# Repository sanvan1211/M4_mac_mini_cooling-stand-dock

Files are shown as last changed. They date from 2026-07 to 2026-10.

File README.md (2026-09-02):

# M4 Mac Mini Cooling Stand / Dock
 
An elevated cooling stand for the Apple M4 Mac mini, designed from scratch in Onshape. It lifts the mini off the desk, mounts a 120mm fan underneath that blows cool air up into the mini's bottom intake, and adds RGB underglow, powered over USB with a single on/off switch.
 
My first CAD project, built through [Hack Club Stardance](https://stardance.hackclub.com/home) to learn CAD. There is a very simply electronics component to this project (wiring the fan + switch) 

Link to design on Onshape: [Mac Mini Cooling Dock]((https://cad.onshape.com/documents/3fbcf659d7555b2671177b8a/w/d5bac3fdae6cccac52d5566e/e/496516c27ea7f88feafa57b4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))
 
> **Status:** parts arrived 
- Amazon: razer kunai fan (arrived)
- Aliexpress: wires and additional electronics + heat inserts
- HACKCLUB Printing Legion

> 
 
## How it works
 
The enclosure sits under the mini. A 120mm aRGB fan mounts to the underside of the top plate and blows **up** through a central airflow cutout into the mini's intake. Intake air reaches the fan through vent slots on all four walls. Fan + LEDs run over USB (dock or wall adapter), with one rocker switch cutting power to both.
 
```
USB-A power -> trunk cable (switch inline) -> Y-splitter
   -> boost cable (5V->12V) -> fan motor (4-pin PWM)
   -> aRGB controller       -> fan LEDs (3-pin aRGB)
```
 
## Specs
 
| Feature | Spec |
|---|---|
| Footprint | 130 × 130 mm |
| Plate thickness | 6 mm |
| Wall height | 32 mm (fits the 25 mm fan with clearance) |
| Airflow cutout | ~108 mm, radiused inlet to reduce flow separation |
| Fan mounting | 4 bosses + M4 heat-set inserts, 105 mm pattern |
| Reinforcement | Corner gussets bracing bosses to walls |
| Venting | Vertical slots on all four walls |
| Rear | Switch cutout (19.2 × 12.7 mm) + cable hole (~10 mm) |
 
## Files
 
- **[BOM.md](BOM.md)** — full parts list, links, cost (~$70 core build)
- **[reflections.md](reflections.md)** — what I learned building it
- `cad/` — STEP (source) + STL (for printing)
## Assembly notes
 
- Melt M4 heat-set inserts into the four bosses.
- Bolt the fan to the underside, airflow arrow pointing **up**.
- Splice the switch inline on the USB 5V wire, then split to the boost cable (motor) and aRGB controller (LEDs).
- Walls are 8 mm — thicker than the switch's snap clips, so it's friction-fit for v1 (thinned pocket planned for v2).
- Add silicone feet for grip and a small air gap.

## Roadmap
 
- [ ] Print v1 and test-fit
- [ ] Assemble and verify wiring
- [ ] Thermal test: temps with stand off vs. on
- [ ] v2 tweaks from the print
- [ ] Future: CFD airflow sim

## Schematics: 


## Screenshots in onshape 



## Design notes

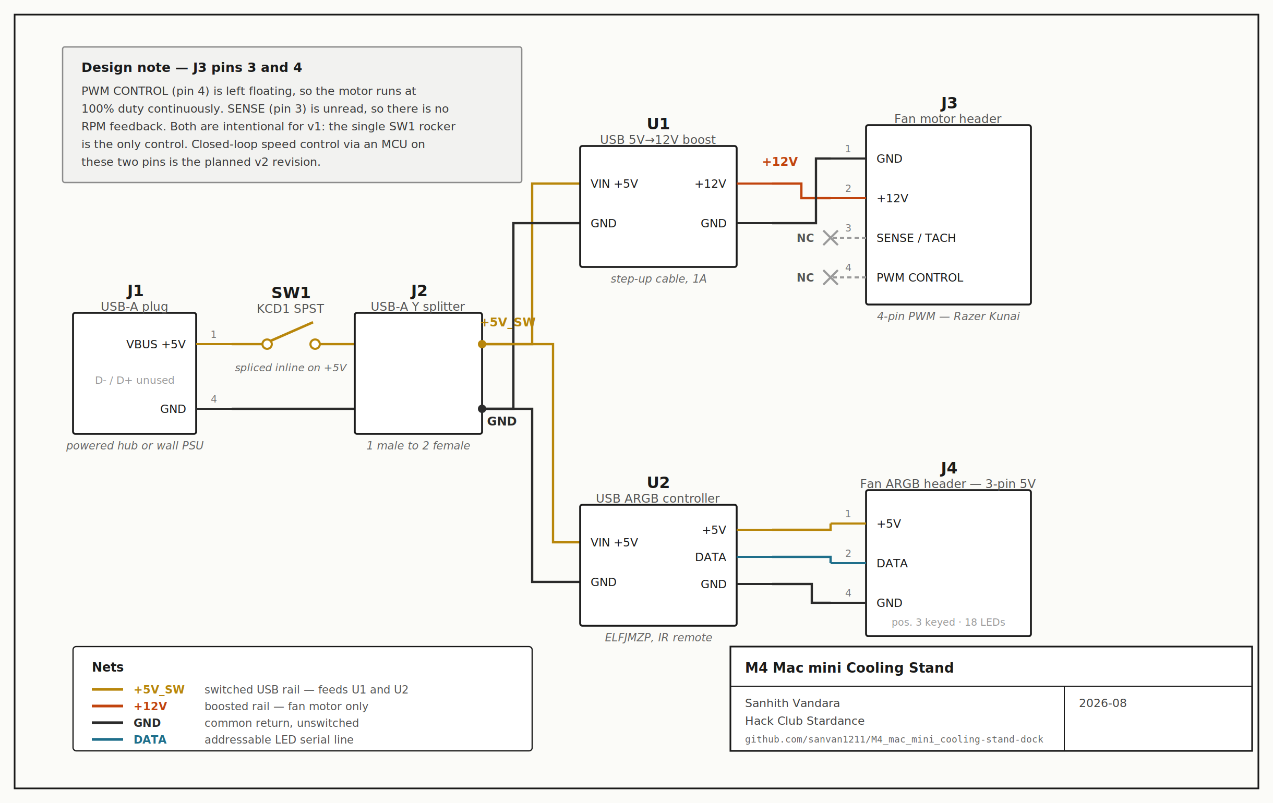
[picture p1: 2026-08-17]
SCHEMATICS/schematic.png

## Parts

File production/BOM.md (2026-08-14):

# Bill of Materials — M4 Mac Mini Cooling Stand / Dock

**Project:**  cooling stand for the M4 Mac mini
**Author:** Sanhith Vandara
**Version:** v2 (A-tier submission)
**Last updated:** August 2026

**Requested funding: $64.50 against the $120 A-tier budget.**

Commodity parts are sourced from AliExpress. Two parts stay on Amazon for spec reasons
documented below. Prices are pre-order estimates — confirm against the live listing before
ordering, since AliExpress pricing moves and listings are frequently relisted.

---

## Parts

| # | Part | Purpose | Source | Est. price |
|---|---|---|---|---|
| 1 | Razer Kunai Hydraulic 120mm aRGB Fan | Main cooling fan + underglow | Amazon | $35.00 |
| 2 | USB 5V→12V step-up cable (3/4-pin fan end) | Boosts USB 5V to 12V for the fan motor | AliExpress | $2.00 |
| 3 | ELFJMZP USB 5V 3-pin ARGB controller | Drives the fan LEDs from USB | Amazon | $10.00 |
| 4 | USB-A 1→2 Y splitter cable | Splits switched power to fan + LED branches | AliExpress | $1.50 |
| 5 | USB 2.0 A-male to A-female extension (1m) | Trunk cable — switch splices inline here | AliExpress | $1.50 |
| 6 | KCD1 mini rocker switch (5-pack) | Master on/off | AliExpress | $1.80 |
| 7 | M4 brass heat-set inserts (20-pack) | Threads in the printed bosses | AliExpress | $2.20 |
| 8 | M4 × 20mm machine screws (20-pack) | Mount the fan into the inserts | AliExpress | $1.80 |
| 9 | Heat-set insert soldering tips | Seats the brass inserts squarely | AliExpress | $3.00 |
| 10 | Heat shrink tubing assortment | Insulate the switch splice | AliExpress | $1.50 |
| 11 | Silicone adhesive feet (20-pack) | Grip + small bottom air gap | AliExpress | $1.20 |
| 12 | PETG filament — 150 g consumed | Prints the enclosure | Amazon | $3.00 |
| | **Total** | | | **$64.50** |

Amazon: $48.00 · AliExpress: $16.50 · **A-tier headroom remaining: $55.50**

**Filament is costed at material consumed, not spool price.** The enclosure uses ~150 g of
a 1 kg PETG spool at ~$20/kg, so the material cost of one unit is $3.00. Note that filament
is not sold in 150 g units — the smallest practical purchase is either a 1 kg spool (~$20)
or a 250 g sample spool (~$8–10). See the pro-rating note below.

Full links are in `BOM.csv`. Spec-critical parts carry direct item links; interchangeable
commodity parts carry AliExpress category search URLs, which stay valid when individual
listings are relisted.

## Covered elsewhere — not funded by this BOM

| Item | Covered by |
|---|---|
| Soldering iron | Hackpad Soldering Iron Grant — $18, one-time |
| Enclosure print service | Printing Legion Grant — $5 shipping credit, under 300 g (optional alternative) |
| Digital calipers | Already owned |
| Hot glue gun | Already owned — seats the switch, not the inserts |

---

## Two parts that could not be substituted

**ARGB controller — stays on Amazon.** Nearly every ARGB controller sold on AliExpress
draws power over **SATA**, from a desktop PSU. This build has no PSU; the entire power
topology runs from a single USB-A source. A SATA controller would either not work or
require an additional USB→SATA adapter, adding a part and a failure point to save about
$7 on a budget with $58 of slack. The USB-native ELFJMZP unit is kept.

**Step-up cable — connector type matters.** Most 5V→12V USB boost cables terminate in a
**5.5 × 2.1 mm barrel jack**, which will not mate with a PC fan. The required variant ends
in a 3-pin/4-pin fan connector. Confirm the connector in the listing photos before ordering.

---

## What changed from v1

The v1 BOM totalled ~$134, sourced entirely from Amazon, with a separate tools table.

- **Fan kept as-is.** The Razer Kunai is the one line where the brand buys something real —
  hydraulic bearing, 18 addressable LEDs, a known noise profile. Held at $35.
- **Interchangeable parts moved to AliExpress**, saving ~$55: cables, switch, fasteners,
  heat shrink, feet. Identical specs; the Amazon premium was markup, not quality.
- **Two parts deliberately not moved** — see the section above.
- **Multi-packs downsized.** 50 inserts and a 10-pack of switches exceeded what one build
  needs; 20-packs and 5-packs cost less and waste less.
- **Filament re-added at consumed cost ($3.00), not spool cost ($20).** v1 charged a full
  1 kg spool to a build that uses 150 g.
- **Soldering iron removed ($22).** Covered by the Hackpad grant.
- **Insert-setting tips added ($3).** The iron alone cannot seat inserts squarely.
- **Consolidated to one BOM.** v1 had a `.md` and a `.csv` that disagreed on totals.
  `BOM.csv` is the source of truth; this file mirrors it.

## Sourcing and sequencing notes

- **Claim the Hackpad iron before ordering tips.** Insert tips thread onto the iron and
  thread standards differ between models. Confirm which iron ships, then buy matching tips.
- **AliExpress ships in roughly 2–5 weeks.** The iron gates assembly — both the inserts and
  the switch splice need it. Order early.
- **Buy from as few sellers as possible.** Ten orders means ten shipments and ten chances
  for shipping fees to creep in.
- **Prefer a fluid or hydraulic bearing** if substituting the fan later. This sits on a desk
  at ear level, and sleeve-bearing fans whine.
- **Filament pro-rating.** This BOM lists $3.00 — the value of plastic actually consumed. A
  spool cannot be bought in 150 g units, so the real out-of-pocket purchase is ~$20 for 1 kg
  (leaving 850 g for future prints) or ~$8–10 for a 250 g sample spool. If reimbursement is
  tied to receipts rather than consumption, submit the spool price instead; the budget
  absorbs it either way ($81.50 of $120 at full spool price).
- **Insert-setting temperature:** roughly 20–40 °C above print temperature. PETG prints at
  230–250 °C, so set the iron near 260–270 °C. A hot glue gun tops out around 200 °C and
  cannot do this job.

---

## Key specifications

**Fan — Razer Kunai 120mm**
- Dimensions: 120 × 120 × 25 mm
- Rated voltage / current: 12V DC / 0.28 A
- Connectors: 4-pin PWM (motor) + 3-pin 5V aRGB (lighting)
- Mounting: standard 120mm pattern — 105 × 105 mm hole square, M4 screws
- 18 addressable LEDs

**Enclosure (3D printed)**
- Footprint: 130 × 130 mm
- Plate thickness: 6 mm
- Wall height: 32 mm (houses the 25 mm fan with clearance)
- Central airflow cutout: ~108 mm, radiused inlet to reduce flow separation
- Fan mounting: 4 bosses with M4 heat-set inserts, corner gussets for support
- Venting: vertical intake slots on all four walls
- Rear: switch cutout (19.2 × 12.7 mm) + cable exit hole (~10 mm)
- Print weight: ~150 g (under the Printing Legion 300 g limit)

**Power / wiring topology**
```
USB-A power (dock or wall)
   -> trunk cable (switch spliced inline on the 5V wire)
      -> Y-splitter
         -> boost cable (5V->12V) -> fan motor (4-pin PWM)
         -> aRGB controller       -> fan LEDs (3-pin aRGB)
```
The single switch cuts power to both the fan motor and the LEDs at once.

---

## Notes

- **Power source:** runs off a powered USB-A source (dock or wall), independent of the
  mini's ports — keeps the mini's ports free and avoids drawing the combined fan + LED
  current through one port.
- **Switch fit:** walls are 8 mm thick; the KCD1's snap clips want ~2 mm, so the switch is
  friction-fit and hot-glued for v1. A thinned mounting pocket is a planned v2 improvement.
- **Airflow:** fan blows **up** into the mini's intake. Wall vents are **intake** for the
  fan; the mini exhausts its own hot air out its rear, above the enclosure.
- **Fan speed:** the PWM pin is currently unconnected, so the motor runs at 100% duty.
  Closed-loop speed control is the obvious use of the remaining headroom.

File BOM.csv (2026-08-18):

Item | Category | Purpose | Source | Est. Price (USD) | Link | Link Type
Razer Kunai Hydraulic 120mm aRGB Fan | Fan | Main cooling fan + underglow | Amazon | 28.00 | https://www.amazon.com/Razer-Kunai-Hydraulic-120MM-aRGB/dp/B09JRMGLQF | item
USB 5V to 12V Step-Up Cable (3/4-pin fan end) | Power | Boosts USB 5V to 12V for fan motor | AliExpress | 2.00 | https://www.aliexpress.com/item/1005006048065687.html | item
3-Pin ARGB USB Controller | Lighting | Drives fan LEDs from USB | Amazon | 7.00 | https://www.amazon.com/ELFJMZP-ARGB-LED-Controller-3-Pin/dp/B0FLY3J3YZ | item
KCD1 Mini Rocker Switch | Switch | Master on/off for unit | AliExpress | 1.50 | https://www.aliexpress.com/w/wholesale-kcd1-rocker-switch.html | search
M4 Brass Heat-Set Inserts (20-pack) | Fasteners | Threads in printed bosses | AliExpress | 2.20 | https://www.aliexpress.com/w/wholesale-m4-brass-heat-set-insert.html | search
M4 x 20mm Machine Screws (20-pack) | Fasteners | Mount fan into inserts | AliExpress | 1.80 | https://www.aliexpress.com/w/wholesale-m4-hex-socket-cap-screw.html | search
Heat Shrink Tubing Assortment | Wiring | Insulate switch splice | AliExpress | 1.50 | https://www.aliexpress.com/w/wholesale-heat-shrink-tube-assortment-kit.html | search
PETG Filament - 150g consumed | Materials | Prints the enclosure | AliExpress | 3.00 | https://www.aliexpress.com/w/wholesale-petg-filament-1-75mm.html | search
Hackpad Soldering Grant | Grant | Covers soldering/tooling costs | Hack Club | 18.00 |  | grant
TOTAL |  |  |  | 65.00

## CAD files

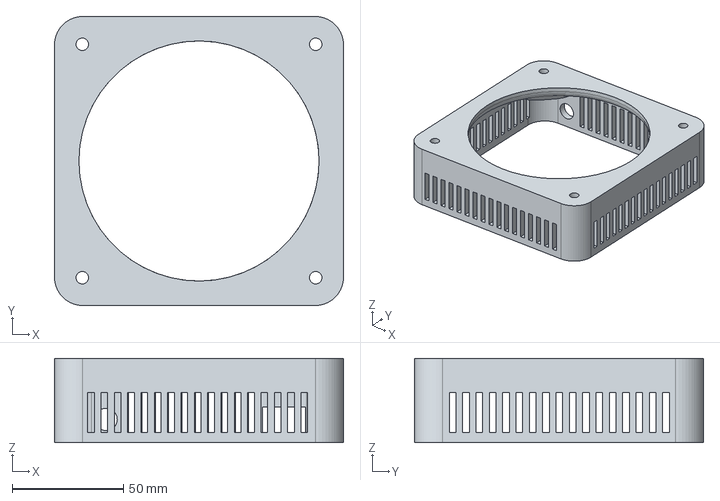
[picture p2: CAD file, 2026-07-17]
CAD/m4_mac_mini_cooling_dock.step
130.0 x 130.0 x 38.0 mm

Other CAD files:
production/m4_mac_mini_cooling_stand.stl

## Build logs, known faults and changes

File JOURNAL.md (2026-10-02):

# M4 Mac mini cooling dock project Journal

## This is my journal for this project

#### I am doing this project for a few different reasons:

1. To improve my CAD skills.
2. To keep my Mac mini cool during heavy workloads.
3. To have fun building small engineering projects.

This project is being completed through Hack Club.

### Tools/Software used: 
Claude - Drafting ideas, searching for similar projects, 
Onshape- CAD Software 

# Entry 1: setting up Onshape and Selecting a fan for project 
#### July 13 2026: 14:30-16:50 hours 

### Fan Comparison

| Fan | Approx. Price | Connector Type | Pros | Cons | Decision |
|---|---:|---|---|---|---|
| **Arctic P12 A-RGB** | ~$16 ($7 on sale (amazon) | Standard 4-pin PWM + 3-pin 5V ARGB | Affordable, quiet, excellent airflow, low power consumption, easy to wire | Simpler appearance than the Razer fan | Excellent value and a strong alternative |
| **Razer Kunai 120mm ARGB** | ~$25–45 | Standard 4-pin PWM + 3-pin 5V ARGB | Premium design, customizable lighting, quality construction, compatible with USB-to-12V conversion | More expensive and slightly louder at higher RPMs | ** Selected for the project** |
| **Corsair iCUE LINK LX120 RGB** | ~$35–45 | Proprietary Corsair iCUE LINK | High-quality fan with premium lighting effects | Requires Corsair's proprietary ecosystem and controller, making integration more difficult | Not selected due to unnecessary complexity |
|**Noctua NF-P12 redux-1700 PWM** | $16 | Standard 4-Pin PWM + 3 pin 5V A-RGB| affordable| Good value and strong alternate | boxy-like shape 

https://m.media-amazon.com/images/I/611T+f1qgRL._SX385_.jpg

When selecting a fan for this project, I considered three main factors: **compatibility**, **ease of integration**, and **overall appearance**.

While the **Arctic P12 A-RGB** offers the best value for the money, I ultimately chose the **Razer Kunai 120mm ARGB** because I wanted the finished build to be both functional and visually appealing. Since this is my first hardware project through **Hack Club Stardance**, I wanted to create something I would be proud to display and document and share with others.

Unlike the **Corsair iCUE LINK LX120**, which relies on a proprietary ecosystem, the Razer Kunai uses standard **4-pin PWM** and **3-pin 5V ARGB** connectors. This makes it much easier to power and integrate into a custom USB-powered cooling stand without requiring additional proprietary hardware.

I also already own several Razer products, including a **Razer Basilisk (V3) mouse **, **Razer x Gillette razor**, and **Razer Kraken X headset**. As a result, I have developed an appreciation for Razer's design language and product aesthetic and choosing the Kunai allows the project to fit naturally alongside the rest of my setup.

The customizable lighting adds a polished, premium appearance to the final build. Although it does not improve cooling performance, it makes the project more engaging to showcase in photos, videos, and GitHub documentation. I also have the Razer Synapse app installed on my Mac mini- so integrated it with the fan and my mouse would be cool as well. 

The Razer Kunai offers the right balance between performance, compatibility, and aesthetics. While it costs more than the Arctic alternative, I believe the improved appearance and straightforward integration make it the best fit for this project and my learning goals.

I stumbled upon some CAD models of a very similar design that I want to implement in my final design:



https://makerworld.bblmw.com/makerworld/model/USf0e74c0e39cc1d/design/2025-01-12_810aa729b34ec.jpg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,w_1000/format,webp 

https://makerworld.bblmw.com/makerworld/model/USf0e74c0e39cc1d/757755172/instance/b3691a0717b74142.png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

https://makerworld.bblmw.com/makerworld/model/USd09a412849dba9/design/2025-08-04_63280fa71a038.jpg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,w_1000/format,webp

After 'Clauding' and searching the internet- ive came up with this brainstorm using canva: 



# Entry 2: Desining the dock in onshape 
#### July 14 2026 

Today was one of those days where I got humbled, I did not know CAD was going to be this tedious. 

I sat down thinking I'd knock out a decent chunk of the stand in a couple of hours. In my head it was basically, "draw a square, cut a few holes, done." Instead, I spent the first hour just learning how Onshape actually wants you to think. It's funny because I'm so used to writing code (or vibecoding) where you can usually figure out what's wrong from an error message. CAD isn't like that at all. If you click the wrong face, forget a constraint, or select one extra sketch region, the entire feature changes and you don't even realize why. Even if its off by a few degrees or millimeters, the entire design can be the opposite of what you intended for. 

I started by creating the base plate for the stand. I sketched out a **150 mm × 150 mm** square, learned how to fully define a sketch with dimensions, and extruded it into a **4 mm thick** plate. That alone taught me more than I expected. I finally understood why people stress making sketches "fully constrained" instead of just eyeballing everything.

After that I worked on the airflow opening. The whole point of this project is to cool the Mac mini better, so getting the fan placement right is one of the most important parts. I cut the large center opening and then added the **four 4.3 mm mounting holes** using the standard **105 mm mounting pattern** for a 120 mm fan. It took me way longer than it probably should have because I kept accidentally selecting the wrong geometry.

At one point I genuinely thought I had destroyed my entire model.

I used **Extrude and Remove** on the mounting holes, hit the green checkmark, and suddenly all of my circles disappeared. My first thought was, "Great... I somehow deleted everything." After a few minutes of panicking (and almost reaching for Ctrl+Z), I realized Onshape was actually doing exactly what it was supposed to do—the sketch gets consumed once it becomes a real feature. 

 I imported a **STEP model of the M4 Mac mini** into Onshape so I could design around the actual computer instead of guessing dimensions. Seeing the Mac mini sitting inside my workspace made the project feel a lot more real. Eventually I'll use that model to make sure the stand, fan, and mounting points all line up correctly before I ever print anything.

The biggest lesson today was that CAD required A LOT of patience.

I came into this project thinking my experience with programming would make learning CAD pretty easy. Instead, I realized they're almost opposite ways of thinking. Programming is logical and sequential. CAD is incredibly visual and detail-oriented. Tiny decisions you make at the beginning affect everything that comes after. It's honestly been a humbling experience.

Even though I probably spent more time troubleshooting than actually designing, I ended the day with a completed base plate, a proper airflow cutout, and correctly spaced fan mounting holes. 

I'm definitely still a beginner, and there were moments today where I questioned if I was doing anything correctly. (But compared to where I was this morning) staring at a blank workspace with no idea where to click—I can already see progress. That's probably the coolest part of this project so far. 







This is a mac mini display I used as refernce while working on my design: 
https://grabcad.com/library/mac-mini-m4-2024-1





# Entry 3: Applying Fluid Dynamic Principles to the body & getting better at CAD
#### July 16 2026

Today was probably the day where CAD finally started making sense.

When I first started this project, every little thing felt like a battle with the software. I was constantly asking Claude where to click, what tool to use, or what happend to my circles. Today was different though. I was actually able to navigate sketches, change dimensions, and make design decisions without needing someone (or some LLM) to walk me through every single step.

I’m finally starting to get the hang of CAD.

The main goal today was finishing the rest of the enclosure body and making the airflow design cleaner.

The first thing I worked on was the intake opening. Originally, the opening had sharp edges, which technically works, but it isn't ideal for airflow. I decided to add fillets and smooth out the transition into the enclosure.

### Radiused inlet and computational fluid dyanamics (CFD)

The engineering principle behind this design is a **radiused inlet**. Instead of forcing incoming air to make a sudden **90-degree turn** around a sharp edge, the rounded surface creates a smoother transition that allows the airflow to follow the intended path. This reduces the likelihood of **flow separation**, where air detaches from the surface and creates recirculation regions, increased turbulence, and inefficient airflow patterns. By maintaining smoother streamlines and reducing stagnant zones near the intake, a radiused inlet can improve the overall efficiency of the cooling system.

To understand how inlet geometry affects airflow behavior, computational fluid dynamics (CFD) simulations can be used to visualize velocity changes and flow separation regions. The figure below demonstrates how airflow behaves around an intake opening. Areas of lower velocity (blue regions) indicate regions where airflow slows down, which can correspond to recirculation zones and potential flow separation. 



Sharp edges can create abrupt changes in flow direction, causing the airflow to detach from the surface and form turbulent wake regions behind the intake. By introducing a radiused inlet, the transition into the opening becomes smoother, allowing streamlines to remain more attached and reducing areas of stagnant airflow.

This same principle applies to the enclosure design. A rounded fan intake reduces sudden pressure changes at the entrance, improving airflow consistency and allowing the cooling fan to operate more efficiently.

Source:
"Trust me bro", (jk): 
- Anderson, J. D. *Fundamentals of Aerodynamics*, 6th Edition, McGraw-Hill Education, 2017.
- NASA Glenn Research Center — Boundary Layer and Flow Separation Concepts: (https://www1.grc.nasa.gov/beginners-guide-to-aeronautics/boundary-layer/)
- https://www.researchgate.net/publication/259889963_On_The_Use_Of_InflowOutflow_Boundary_Conditions_In_Incompressible_Internal_Flow_Problems_Using_Smoothed_Particle_H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

I’m not claiming that adding a few fillets will magically drop temperatures by 20 degrees (and thats not the point of this project), but it was cool being able to apply actual fluid dynamics concepts to something I was designing. Even the small details like edge geometry can matter when designing parts that interact with airflow, even on a miniscule applciation like this-cooling an already cool Mac Mini. 

## Fan Reference Dimensions

For the fan mounting system, I used the specifications from Razer’s Kunai Hydraulic Chroma Case Fans as a reference:

- Dimensions: **120mm × 25mm × 120mm**
- Fan size: **120mm**
- Thickness: **25mm**

Sources:
- https://mysupport.razer.com/app/answers/detail/a_id/5732/~/razer-kunai-hydraulic-chroma-case-fans-%7C-rc21-01800-support-%26-faqs
- https://www.youtube.com/watch?v=nCtzMYYiK6Q





### Reinforcing the Fan Mounts

After fixing the airflow, I moved onto strengthening the fan mounting points.

I went back and resized the corner screw holes from **4.3mm to 5.6mm**. Then I created raised mounting bosses around each hole. These add extra material around the mounting points, making the enclosure stronger and giving the screws/inserts more support.

Originally, I was planning on saving these for a later version, but I decided to try making them myself. The gussets connect the fan bosses to the walls of the enclosure, which creates a stronger structure and helps spread out stress instead of concentrating it around one small area.

### Final Result

After a lot of filleting, extruding, tweaking dimensions, and fixing small mistakes, I ended up with this version:





Completed today:
- Smoothed and radiused airflow inlet
- Improved interior airflow 
- Resized fan mounting holes to 5.6mm
- Added reinforced fan bosses
- Added corner gussets for extra structural support
- Added interior and exterior fillets
- Adjusted and finalized bottom geometry

## Remaining Tasks
- Add vents for airflow
- Add switch cutout ( i might do this)
- Add silicone pad mounting locations ( not that important)
- Final CAD cleanup
- Export STL/STEP files for manufacturing and testing
- Put the M4 MAC MINI cad alongside this

I also might do an airflow simulation later to see how it performs and actually visualize those CFD applications on my design. 

## Entry 4: Adding the side vents and finishing the design: 
#### July 17, 2026

Today I finished up my design, its pretty cool that this was my first CAD project and I was able to use this software for something practical. Today was mostly about adding side vents and holes for cables and the pwr switch. 

### Side Ventilation

I designed ventilation slots on all four side walls to improve airflow into the enclosure. Instead of using circular holes, I went with long horizontal slots because they provide a cleaner appearance while still allowing a large amount of air to reach the cooling fan.



To create the vents, I:
- Created sketches directly on the side wall faces.
- Used center-point rectangles to define each vent slot.
- Dimensioned the slots for consistency.
- Used **Extrude Cut** to remove material.
- Applied **Linear Pattern** to evenly replicate the slots across each wall.
- Used **Mirror** where appropriate to keep the vent layout symmetrical between opposite sides.

The rear panel was designed with a more open layout since it also needs to accommodate the power switch and cable routing.

### Power Switch & Cable Openings

After finishing the ventilation, I added dedicated openings for the fan's power switch and power cable on the back panel. These cutouts ensure the fan can be powered externally without interfering with the airflow path or requiring modifications after printing.

The switch I will be using is a: DaierTek mini rocker switch with a 19.2 × 12.7 mm panel cutout

### CAD Skills:
- Sketching on non-horizontal faces
- Center-point rectangles
- Dimensioning sketches
- Extrude Cut
- Linear Pattern
- Mirror
- Planning feature placement around existing geometry

Overall, today's progress moved the enclosure much closer to a printable prototype. Most of the external airflow and hardware features are now complete, leaving mainly refinement and testing before the first print.





# Entry 5: Schematics: 

Today I added schematics, my design has been reviewed by Hack Club, I need to fix a few things with the repo and add schematic. 



# Reflections — My First CAD Project
 
This was my first CAD project ever. No class, no YouTube tutorials, no prior experience. Just me, Onshape, an idea for a cooling stand, and a lot of trial and error. But I do have *Claude Pro*, and that saved me multiple times but anyway here's what I learned.
 
## What I thought CAD would be
 
Going in, I figured CAD would be pretty easy. Draw a few lines, grab the little arrows, pull stuff in and out, done. I knew there'd be some math involved, but I didn't realize how much of it would be *geometry* — angles, references, measurements, everything relating to everything else. It's less "drawing" and more "defining exactly where every point lives and how it relates to every other point."
 
The hardest part wasn't the tools themselves. It was taking the picture in my head and actually getting it onto the screen. I'd know exactly what I wanted the stand to look like, and then spend forever figuring out which combination of sketches, extrudes, and fillets would actually produce that shape. There were a *lot* of changes along the way. The design I ended up with is not the design I started with.
 
## Trial and error (with worse error messages)
 
CAD reminded me a lot of programming — it's iterative, you break things constantly, and you fix them one at a time. But there's one big difference: when you write code and something breaks, it *tells* you what went wrong. Syntax error, runtime error, logic error, whatever. You get a hint, or your program just dosent work as intended.
 
CAD doesn't do that. When something's wrong, it just turns red. That's it. No explanation, no error type, no line number. Just red, and you're on your own to figure out what it's mad about. "Sketch could not be solved" became a phrase I saw in my sleep.
 
Honestly though, none of those errors really stuck with me as *the* moment, because I overcame all of them. It was just a constant loop: something breaks, figure out why, fix it, keep moving. That loop got faster the more I did it.
 
## The skills I actually picked up
 
For a first project, I ended up learning way more than I expected:
 
- **Sketching and dimensioning** — center-point and corner rectangles, circles, and the golden rule I learned the hard way: *dimension holes from the center, not the edge* (this is why one of my fan holes was misaligned for a while).
- **Extrudes** — both adding material and cutting through it (Remove / Through all).
- **Fillets** — for looks (rounding the corners into a soft box) and for function (radiusing the airflow inlet and the interior corners).
- **Bosses** — building up thicker cylinders around holes so my M4 brass heat-set inserts would have something to grip.
- **Parametric editing** — when my plate was too thin for the mini's weight, I just changed one number (4mm → 6mm) and watched the *entire* model rebuild itself around it. That was the moment CAD clicked as something powerful, not just fiddly.
- **Linear patterns** — repeating the vent slots across a wall instead of drawing 15 of them by hand.
- **Mirror** — copying features to the opposite side.
- **Sketching on vertical faces** — not just the flat top, which is more disorienting than it sounds.
- **Diagnosing red errors** — the actual core skill of the whole thing.
- **Designing for real-world assembly** — corner gussets for strength, clearance for the fan, cutouts for the switch and cable, and applying fluid dynamics (a radiused inlet to reduce flow separation and turbulence) to actually optimize airflow into the mini.

## How it turned out
 
Really well, I'm proud of it. It went from "I can't get a dimension box to open" to a clean, structurally sound enclosure with vents on all four walls, a switch, a cable pass-through, and airflow I thought about instead of just guessing at.
 
## What's next
 
I can't wait to do more projects. I might try a **liquid-cooled Mac mini** as a future build,  it probably wouldn't improve performance much, but it'd definitely help with thermals and keep things cool. In case I ever decide to sacrifice my Mac mini to OpenClaw.

# Entry 6: Final Build

Component Sourcing
Main chassis: Printed and shipped by Hack Club Printing Legion.
Fan: Sourced from Amazon.
Cables: Sourced from AliExpress.
Design Issues and Future Improvements

Several issues were identified during assembly and testing that will be addressed in the next design iteration:

Restricted Air Intake: The bottom air intake is somewhat restricted due to insufficient clearance beneath the chassis. The next iteration will increase the chassis height and enlarge the side vents to improve airflow.
Undersized Cable Routing Holes: The CAD-designed cable routing holes are too small to accommodate the cables underneath the chassis. These holes will be enlarged in the next iteration to allow for easier cable management and a cleaner assembly.
Fan Mounting Mechanism: The fan was mounted using silicone screws rather than brass inserts. The silicone screws provided a more secure and sturdy mounting solution. The next iteration will revise the brass insert slots to improve fitment and mounting stability.

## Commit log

2026-07-13 Add project journal for Mac mini cooling stand
    Documented project details, fan comparison, and final selection for the Mac mini cooling stand.
2026-07-13 Revise fan selection rationale in JOURNAL.md
    Updated project details, including fan selection and reasons for choosing the Razer Kunai 120mm ARGB over the Arctic P12 A-RGB. Added personal insights and integration considerations.
2026-07-13 Add entry for Onshape setup and fan comparison
2026-07-13 Update time entry in JOURNAL.md
    Adjusted the time entry for setting up Onshape and selecting a fan.
2026-07-13 Enhance fan comparison and add CAD model links
    Updated fan comparison table with additional pricing details and new fan entry. Added links to CAD models for final design implementation.
2026-07-15 Add journal entry on CAD design experience
    Documented the challenges and learning experiences while designing a CAD model for a Mac mini stand using Onshape, including insights on sketching, constraints, and the importance of patience in CAD 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
2026-07-15 Edit JOURNAL.md for better readability
    Rephrased a sentence for clarity and improved flow.
2026-07-17 Revise journal entries for clarity and formatting
    Updated journal entries with corrections and improvements in formatting, including capitalization and clarity. Added detailed descriptions of CAD design progress and fluid dynamics principles applied to the project.
2026-07-17 Add design details for side vents and power switch
    Documented the design process for side vents and power switch openings in the CAD project, including techniques used for creating ventilation slots and ensuring airflow.
2026-07-17 add BOM to repo
    Removed unnecessary separators and updated formatting.
2026-07-17 Add reflections and takeaways from first CAD project
    Document reflections and takeaways from my first CAD project, detailing experiences, challenges, and skills learned.
2026-07-17 Revise README for M4 Mac Mini Cooling Stand
    Expanded the README to include detailed project description, specifications, assembly notes, and roadmap.
2026-07-17 Revise BOM details and component descriptions
    Updated BOM.md to clarify pricing, component usage, and specifications for the cooling stand build.
2026-07-17 Update BOM.csv file
    [(updated)BOM.csv]
2026-07-17 Rename Part Studio 1.stl to m4_mac_mini_cooling_stand.stl
    [m4_mac_mini_cooling_stand.stl]
2026-08-14 Revise BOM details for M4 Mac Mini cooling stand
    Updated project description and funding amounts. Adjusted total costs and clarified filament pricing.
2026-08-14 Update project description in BOM.md
2026-08-17 Add link to Claude AI API in schematic.md
2026-08-17 Enhance README with schematics and screenshots
    Added schematics and screenshots sections to README.
2026-08-17 Correct section title from 'schematics' to 'Schematics'
2026-08-17 Add SVG schematic generation for USB power system
    This script generates an SVG schematic diagram for a USB power distribution system, including components like USB connectors, pins, and wires.
2026-08-17 Move CAD source into CAD/
    [m4_mac_mini_cooling_dock.step]
2026-08-17 Move STL and BOM into production/
    [m4_mac_mini_cooling_stand.stl]
2026-08-17 Update README with electronics details
    Added details about the electronics component for the fan and switch.
2026-08-22 Revise project status and materials in README
    Updated project status and material list in README.
